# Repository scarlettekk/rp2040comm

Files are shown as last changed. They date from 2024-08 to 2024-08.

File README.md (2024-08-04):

# YARLoRa
_**Y**et **A**nother **R**P2040 **LoRa**_

This repository hosts project files for an RP2040-based microcontroller board with a LoRa 915MHz RFM95W transceiver and BLE5201 Bluetooth LE 5.2 module. 

v2 of the board has been completed but it has not yet been tested and there is no software for it yet.
This board was created for the Hack Club OnBoard program.

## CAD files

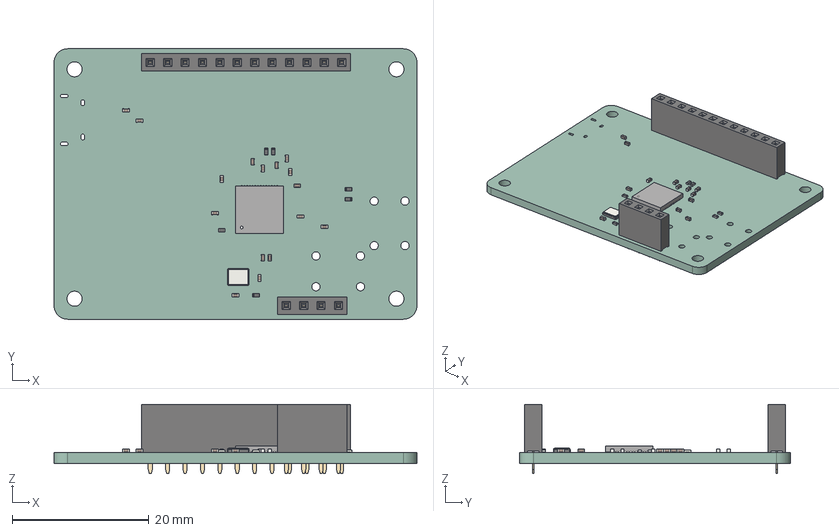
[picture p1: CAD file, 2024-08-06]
board/board.step
53.0 x 39.5 x 10.1 mm
C_0402_1005Metric x 16
R_0402_1005Metric x 6
PinSocket_1x04_P254mm_Vertical
PinSocket_1x12_P254mm_Vertical
QFN_56_1EP_7x7mm_P04mm_EP32x32mm
Crystal_SMD_Abracon_ABM8G-4Pin_3.2x2.5mm
board_PCB

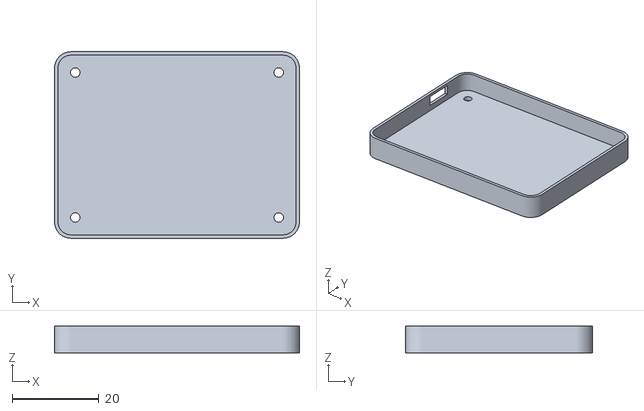
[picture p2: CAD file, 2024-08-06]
case/case_bottom.stl
56.6 x 43.1 x 6.20

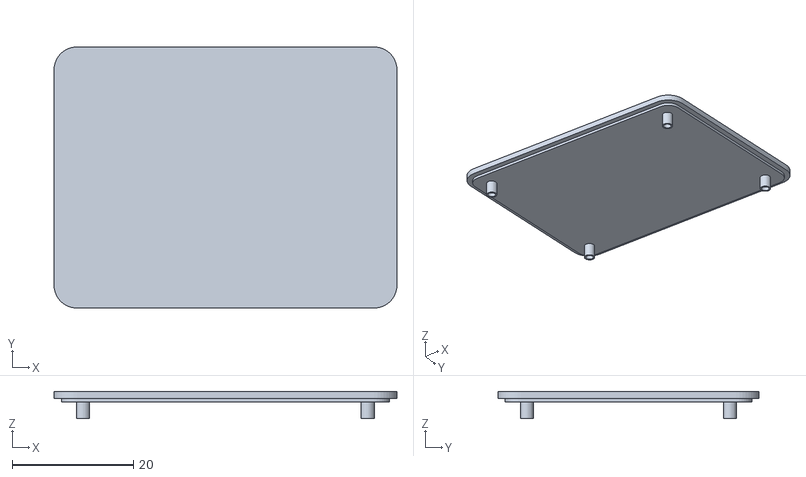
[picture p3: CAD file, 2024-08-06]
case/case_top.stl
56.6 x 43.1 x 4.52

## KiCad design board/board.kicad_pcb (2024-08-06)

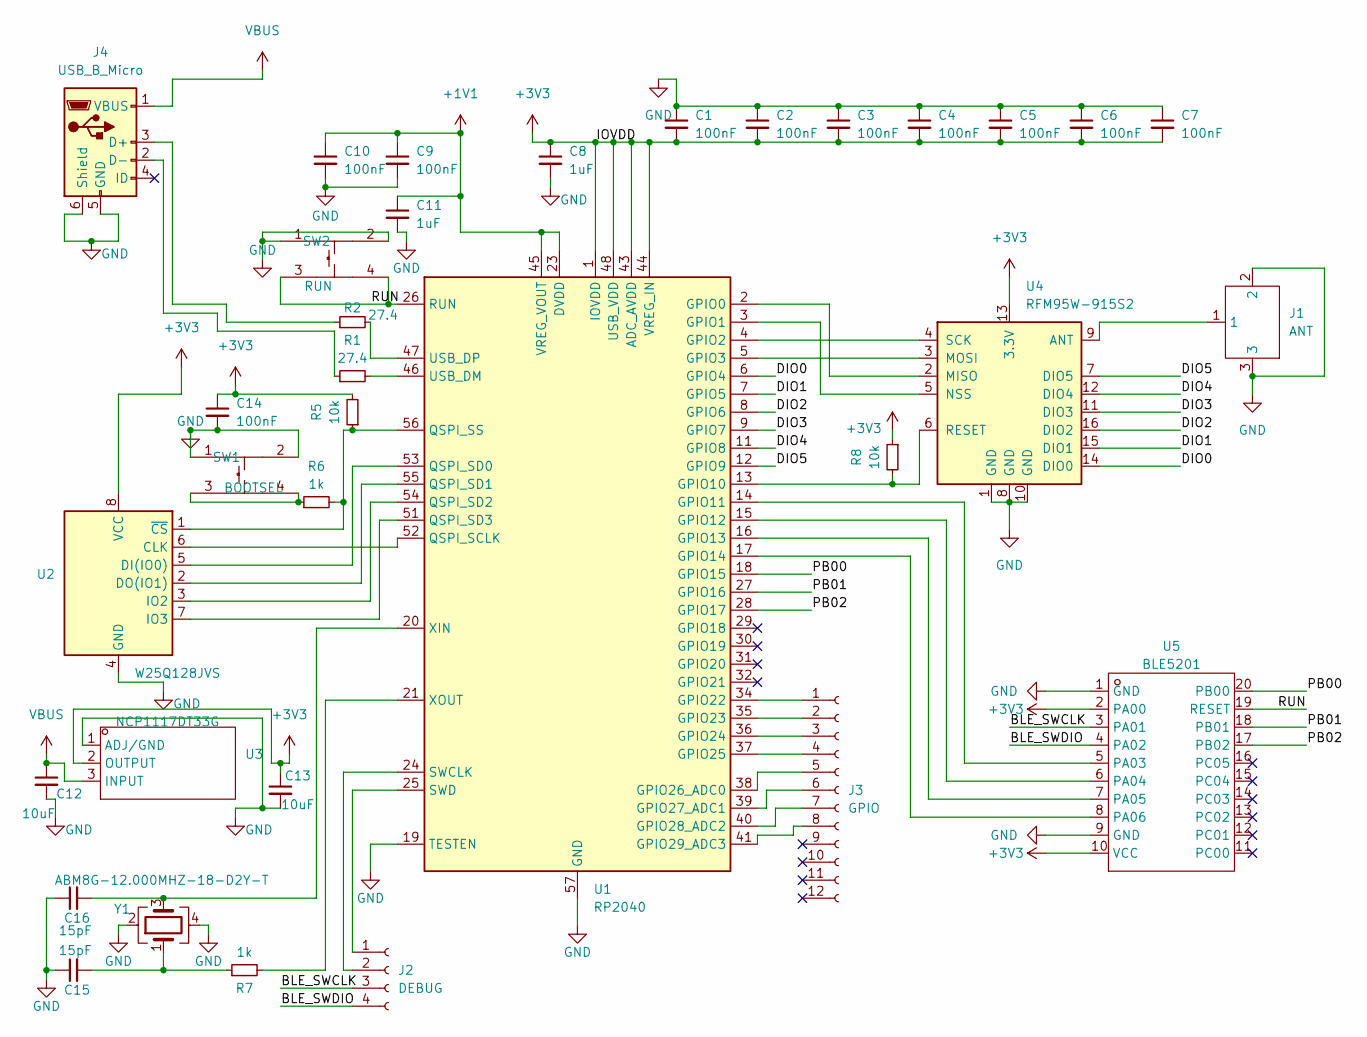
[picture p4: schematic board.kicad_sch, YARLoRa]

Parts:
C1, C2, C3, C4, C5, C6, C7, C9, C10, C14: 100nF; C_0402_1005Metric
C8, C11: 1uF; C_0402_1005Metric
C12, C13: 10uF; C_0402_1005Metric
C15, C16: 15pF; C_0402_1005Metric
J1: ANT; BWU.FL-IPEX1; Manufacturer Part BWU.FL-IPEX1; LCSC Part Name 内针 IPEX
J2: DEBUG; PinSocket_1x04_P2.54mm_Vertical
J3: GPIO; PinSocket_1x12_P2.54mm_Vertical
J4: USB_B_Micro; USB_Micro-B_Amphenol_10118194_Horizontal
R1, R2: 27.4; R_0402_1005Metric
R5, R8: 10k; R_0402_1005Metric
R6, R7: 1k; R_0402_1005Metric
SW1: BOOTSEL; SW-TH_4P-L6.0-W6.0-P4.50-LS6.5; Manufacturer Part K2-1102DP-L3SW-04; LCSC Part Name K2-1102DP-L3SW-04
SW2: RUN; SW-TH_4P-L6.0-W6.0-P4.50-LS6.5; Manufacturer Part K2-1102DP-L3SW-04; LCSC Part Name K2-1102DP-L3SW-04
U1: RP2040; QFN-56-1EP_7x7mm_P0.4mm_EP3.2x3.2mm
U2: W25Q128JVS; SOIC-8_5.23x5.23mm_P1.27mm
U3: NCP1117DT33G; NCP1117DT50G; Manufacturer Part NCP1117DT50G; LCSC Part Name 输入20V 输出5V 1A
U4: RFM95W-915S2; HOPERF_RFM9XW_SMD
U5: BLE5201; Manufacturer Part BLE5201
Y1: ABM8G-12.000MHZ-18-D2Y-T; Crystal_SMD_Abracon_ABM8G-4Pin_3.2x2.5mm

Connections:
+1V1: C9.1, C10.1, C11.1, U1.23 (DVDD), U1.45 (VREG_VOUT), U1.50 (DVDD)
+3V3: C1.2, C2.2, C3.2, C4.2, C5.2, C6.2, C7.2, C8.1, C13.1, C14.1, R5.2, R8.1, U1.1 (IOVDD), U1.10 (IOVDD), U1.22 (IOVDD), U1.33 (IOVDD), U1.42 (IOVDD), U1.43 (ADC_AVDD), U1.44 (VREG_IN), U1.48 (USB_VDD), U1.49 (IOVDD), U2.8 (VCC), U3.2 (OUTPUT), U4.13 (3.3V), U5.2 (PA00), U5.10 (VCC)
/BLE_SWCLK: J2.3, U5.3 (PA01)
/BLE_SWDIO: J2.4, U5.4 (PA02)
/DIO0: U1.6 (GPIO4), U4.14 (DIO0)
/DIO1: U1.7 (GPIO5), U4.15 (DIO1)
/DIO2: U1.8 (GPIO6), U4.16 (DIO2)
/DIO3: U1.9 (GPIO7), U4.11 (DIO3)
/DIO4: U1.11 (GPIO8), U4.12 (DIO4)
/DIO5: U1.12 (GPIO9), U4.7 (DIO5)
/PB00: U1.18 (GPIO15), U5.20 (PB00)
/PB01: U1.27 (GPIO16), U5.18 (PB01)
/PB02: U1.28 (GPIO17), U5.17 (PB02)
/RUN: SW2.3, SW2.4, U1.26 (RUN), U5.19 (RESET)
GND: C1.1, C2.1, C3.1, C4.1, C5.1, C6.1, C7.1, C8.2, C9.2, C10.2, C11.2, C12.2, C13.2, C14.2, C15.1, C16.1, J1.2, J1.3, J4.5 (GND), J4.6 (Shield), SW1.1, SW1.2, SW2.1, SW2.2, U1.19 (TESTEN), U1.57 (GND), U2.4 (GND), U3.1 (ADJ/GND), U4.1 (GND), U4.8 (GND), U4.10 (GND), U5.1 (GND), U5.9 (GND), Y1.2, Y1.4
unnamed: C15.2, R7.1, Y1.1
unnamed: J2.1, U1.25 (SWD)
unnamed: J2.2, U1.24 (SWCLK)
unnamed: J3.1, U1.34 (GPIO22)
unnamed: J3.2, U1.35 (GPIO23)
unnamed: J3.3, U1.36 (GPIO24)
unnamed: J3.4, U1.37 (GPIO25)
unnamed: J3.5, U1.38 (GPIO26_ADC0)
unnamed: J3.6, U1.39 (GPIO27_ADC1)
unnamed: J3.7, U1.40 (GPIO28_ADC2)
unnamed: J3.8, U1.41 (GPIO29_ADC3)
unnamed: J4.3 (D+), R2.1
unnamed: J4.2 (D-), R1.1
unnamed: R6.1, SW1.3, SW1.4
unnamed: U1.2 (GPIO0), U4.2 (MISO)
unnamed: U1.3 (GPIO1), U4.5 (NSS)
unnamed: U1.4 (GPIO2), U4.4 (SCK)
unnamed: U1.5 (GPIO3), U4.3 (MOSI)
unnamed: R8.2, U1.13 (GPIO10), U4.6 (RESET)
unnamed: U1.14 (GPIO11), U5.5 (PA03)
unnamed: U1.15 (GPIO12), U5.6 (PA04)
unnamed: U1.16 (GPIO13), U5.7 (PA05)
unnamed: U1.17 (GPIO14), U5.8 (PA06)
unnamed: U1.52 (QSPI_SCLK), U2.6 (CLK)
unnamed: U1.53 (QSPI_SD0), U2.5 (DI(IO0))
unnamed: U1.55 (QSPI_SD1), U2.2 (DO(IO1))
unnamed: U1.54 (QSPI_SD2), U2.3 (IO2)
unnamed: U1.51 (QSPI_SD3), U2.7 (IO3)
unnamed: R5.1, R6.2, U1.56 (QSPI_SS), U2.1 (~CS)
unnamed: R1.2, U1.46 (USB_DM)
unnamed: R2.2, U1.47 (USB_DP)
unnamed: C16.2, U1.20 (XIN), Y1.3
unnamed: R7.2, U1.21 (XOUT)
unnamed: J1.1, U4.9 (ANT)
VBUS: C12.1, J4.1 (VBUS), U3.3 (INPUT)

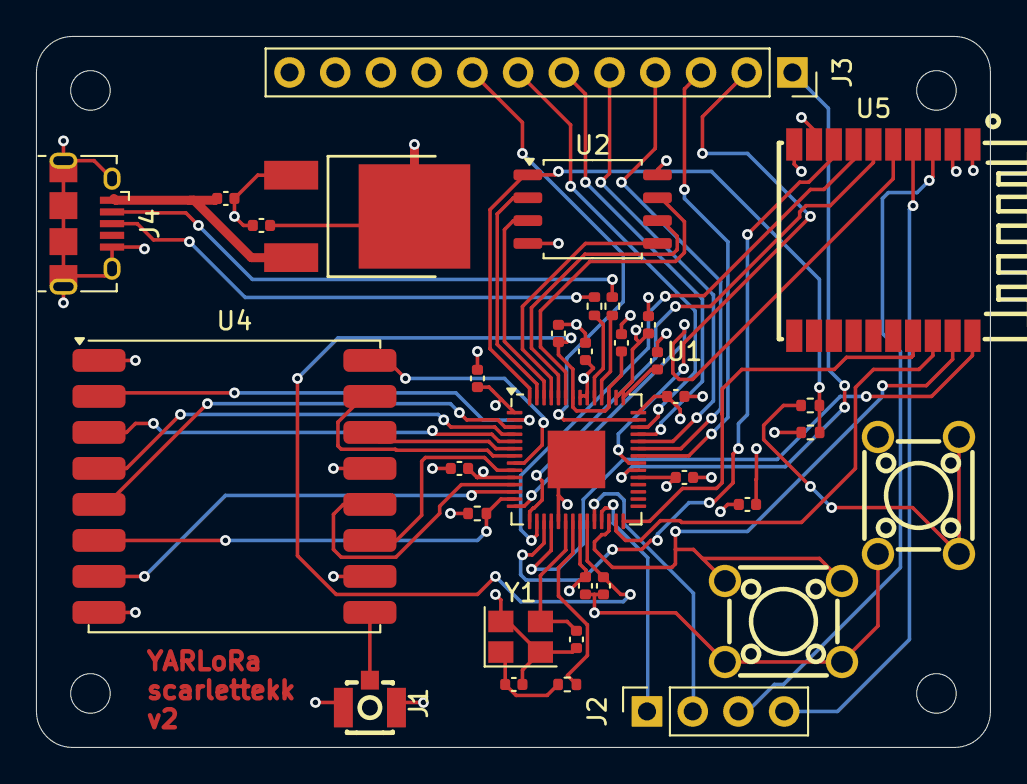
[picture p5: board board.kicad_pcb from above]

Board: 4 copper layers, 53.0 x 39.5 mm, 34 parts (0 on the bottom side), 50 nets.

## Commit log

2024-07-25 add gitignore and initial IOVDD coupling
    [board.kicad_pcb, board.kicad_sch]
2024-07-25 USB hopefully
    [board.kicad_sch]
2024-07-26 implement proper usb C
    [board.kicad_pcb, board.kicad_sch]
2024-07-26 voltage regulator
    [board.kicad_sch]
2024-07-26 flash resistors and BOOTSEL button
    [board.kicad_sch]
2024-07-27 crystal oscillator
    [board.kicad_sch]
2024-07-27 crystal footprint
    [board.kicad_sch]
2024-07-27 switch crystal for a better one
    [board.kicad_sch]
2024-07-27 Finish LoRa schematic and add RUN button
    [board.kicad_sch]
2024-07-27 Appease ERC and add debug header
    [board.kicad_sch]
2024-07-28 board design: hr1
    [board.kicad_pcb, board.kicad_sch]
2024-07-28 board design: hr2
    [board.kicad_pcb, board.kicad_sch]
2024-07-31 board design v1
    [board.kicad_pcb]
2024-07-31 add GPIO
    [board-B_Cu.gbr, board-B_Mask.gbr, board-Edge_Cuts.gbr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]
2024-08-03 schematic v2 ft. ble, license under CC-BY-NC 4.0
    [board.kicad_sch]
2024-08-03 board v2 hour 1
    [board.kicad_pcb, board.kicad_sch]
2024-08-04 board v2 hour 2
    [board.kicad_pcb, board.kicad_sch]
2024-08-04 finish board v2
    [board-B_Cu.gbr, board-B_Mask.gbr, board-CuBottom.gbr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]
2024-08-04 appease jlcpcb (component swaps)
    [board-CuBottom.gbr, board-CuIn1.gbr, board-CuIn2.gbr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]
2024-08-06 add case
    [board.kicad_pcb, board.step, case_bottom.stl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]
2024-08-06 fix case bottom
    [case_bottom.stl]

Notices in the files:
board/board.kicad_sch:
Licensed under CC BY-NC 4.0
